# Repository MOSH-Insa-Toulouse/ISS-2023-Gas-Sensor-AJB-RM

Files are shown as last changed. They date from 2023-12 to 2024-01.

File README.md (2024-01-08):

# ISS 2023: Gas sensor 

### Authors
Romain Moulin & Aude Jean-Baptiste, 5ISS 2023-2024

# Introduction
The objective of this project is to integrate a gas sensor that we made ourselves during a training period at AIME (Atelier Interuniversitaire de Micro Electronique) and send its data over a Lora network to a dashboard to see and analyse the values.

# Initiation to Electronics and Arduino programming
As we both come from a computer science background (4IR-SC), we used the first labs as an introduction to Arduino and Kicad. We tested some small projects from simply making a LED from an Arduino blink to collecting data sent by a Nunchunck (A nintendo WII controller). We also designed an android application able to communicate and interact with an arduino.

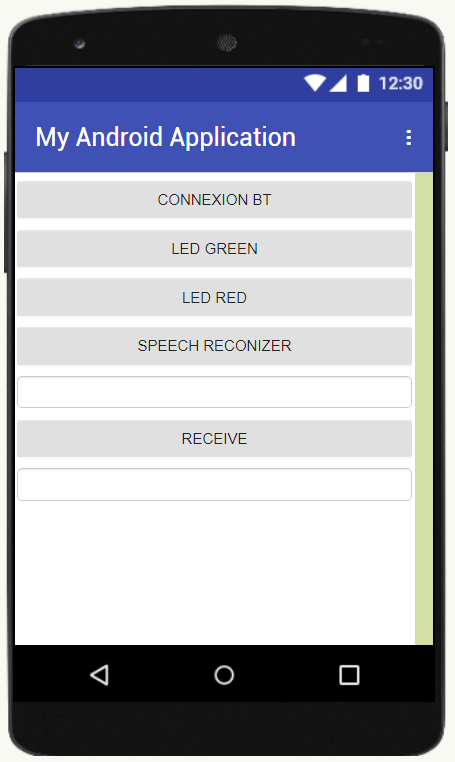
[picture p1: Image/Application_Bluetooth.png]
Screenshot of our Android application
 *Screenshot of our Android application*

These first sessions were really usefull to understand the basics of Arduino programming and electronics. These small projects were a good introduction to the real project of this course.

# Lora network integration

To begin our project, we first tried to connect an arduino to the Lora network. To do so, we used a RN2483 chip made by Microship which is a module that is able to communicate on a Lora network. As this chip only has tiny connectors, we needed to weld the component to a board that would have bigger connectors for the communication with the arduino. The following image features the board with an antenna for the 868MHz frequency band. 

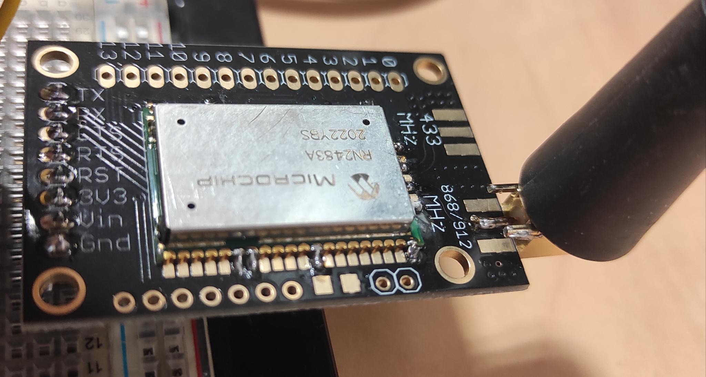
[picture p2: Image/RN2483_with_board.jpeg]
RN2483 Module weld on the board
 *RN2483 Module weld on the board*

After this step, we were able to connect our arduino to the INSA's Lora network. For this, we used *The Things Network* library for arduino, the code is available [here](./Arduino-Code/lora_connection/lora_connetion.ino).
For this, we had used the otaa authentication method. We got the device ID using the library and the application ID and key on the [chirpstack's INSA website](https://srv-chirpstack.insa-toulouse.fr/#/login) (please note that this server is only available if you are directly connected to INSA's network, or using a VPN). 

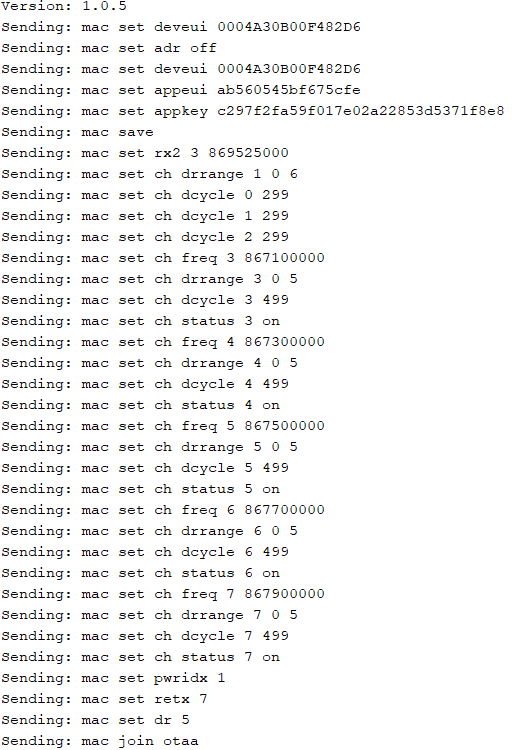
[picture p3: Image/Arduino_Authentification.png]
Authentication of the arduino to the Lora network
 *Authentication of the arduino to the Lora network*

# Integration of the MQ-3B gas sensor

With the established connection, we had to send data to the gateway in order to retrive it and display it on a dashboard. As a first implementation of this application we connected an alreay made gas sensor which is the MQ-3B gas sensor to our arduino. The final montage of our circuit is the following:

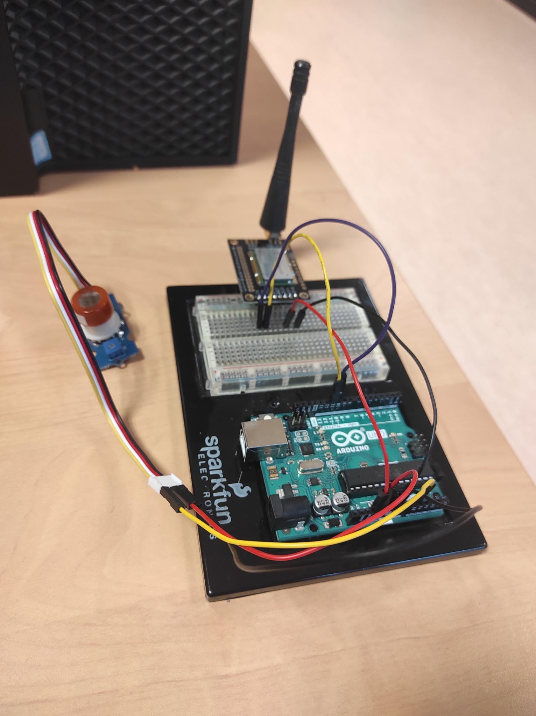
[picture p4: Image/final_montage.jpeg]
Montage of the circuit with the MQ-3B gas sensor
 *Montage of the circuit with the MQ-3B gas sensor*

After that we changed our arduino code to read the value from the gas sensor and send it to our LoRa network. As the max value we can get from the sensor is 1024, we encoded the information on 2 bytes before sending it.

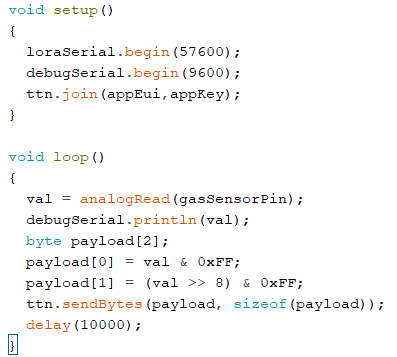
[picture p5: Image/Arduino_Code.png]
*Our arduino setup and loop functions
 *Our arduino setup and loop functions*

# Design of a node-red application

As the data is received by the LoRa network, we could visualize it on the chirpstack web page. However, it is not fitted for a real usage of our gas sensor. A user of gas sensor would like to see the state of the sensor in real time in a dashboard. To do so, we decided to use node-red and MQTT.

MQTT is a communication protocol particulary used for IoT devices. With this protocol there are two kind of nodes, the publisher and the subscribers. Publishers publish data in a topic and subscriber get all the data published on a specific topic. This protocol is supported by chirpstack which automatically upload the data it receives in a MQTT topic. 

Node-red is a web-browser flow editor that helps to easily connect flows. It provides visual coding with blocks for the ease of conception. It also implements dashboard library to display the data is user friendly dahsboards. We used a MQTT subscribe block to get the data from chirpstack that we pipe into a javascript function that decodes the data (it is encoded in base64 by chirpstack). Finaly we send the decoded data to a dashboard block to visualize the data.

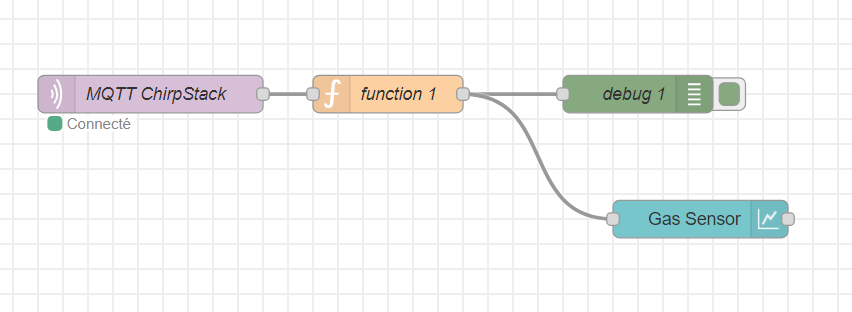
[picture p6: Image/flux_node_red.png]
The node-red flow
 *The node-red flow*

# Test of the MQ-3B solution

To test our sensor, we putted hydroalcoholic gel near it to see if we could see it on our dashboard. This experience was a succes and we were able to see on the dashboard the increase of the gas rate near the sensor.

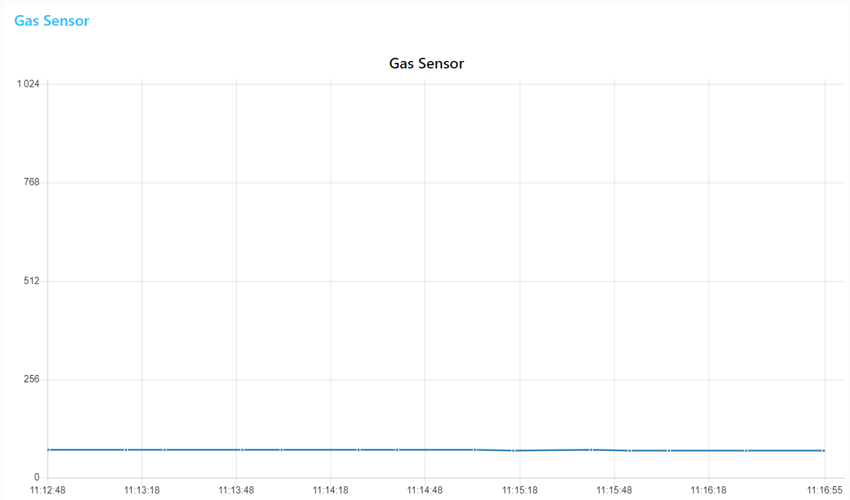
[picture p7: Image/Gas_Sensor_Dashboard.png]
Dashboard for the witness experience in ambient air
 *Dashboard for the witness experience in ambient air*

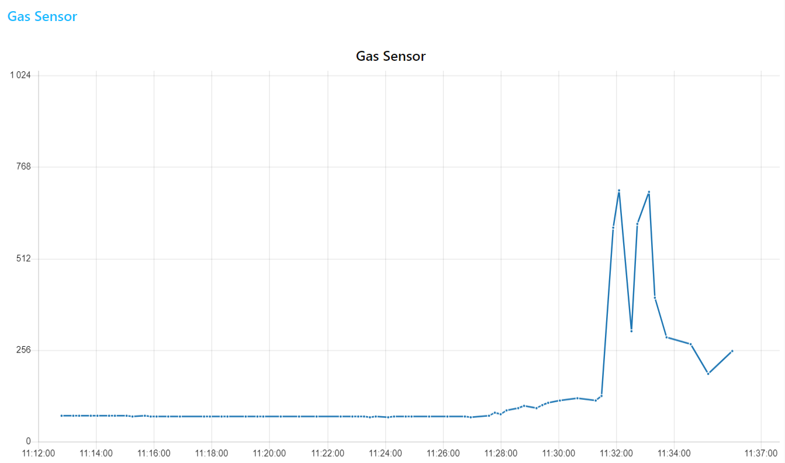
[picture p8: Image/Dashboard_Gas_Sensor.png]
Dashboard for the experience with alcoholic gel
 *Dashboard for the experience with alcoholic gel*

# Integration of our gas sensor from AIME 

The specifications of our gas sensor are detailed in the datasheet (see below). In order to replace the commercial sensor (MQ-3B) by our gas sensor in our previously detailed monitoring solution with Lora and node-red, we need to follow various steps. 

Indeed, our sensor per se is passive; changes in its resistance allow us to monitor gas presence. We will power and control the sensor through an arduino uno and get its data with the ADC (analog digital converter),  like we did with the MQ-3B. 

The screenshots on the following part have been extracted from our Kicad project, that you can find [here](./MOSH). 

## Transimpedance amplifier

The first stage to treat sensor data is a transimpedance amplifier that will allow us to shape the signal for it to be detected by the arduino's ADC. This stage contains 3 low-pass filters with the following cut-off frequencies and roles: 
- filter 1: 16Hz - this filter is here to eliminate as much noise from the sensor as possible
- filter 2: 1.6Hz - this filter should get rid off the 50Hz noise
- filter 3: 1.6kHz - this filter should adapt the signal to the arduino's ADC 

This circuit was simulated on LTSpice to test the properties of the different filters and of the transimpedance amplifier per se. You can find all the related work in [this directory](./ltspice-stuff)

The transimpedance amplifier is featured in the following image. 

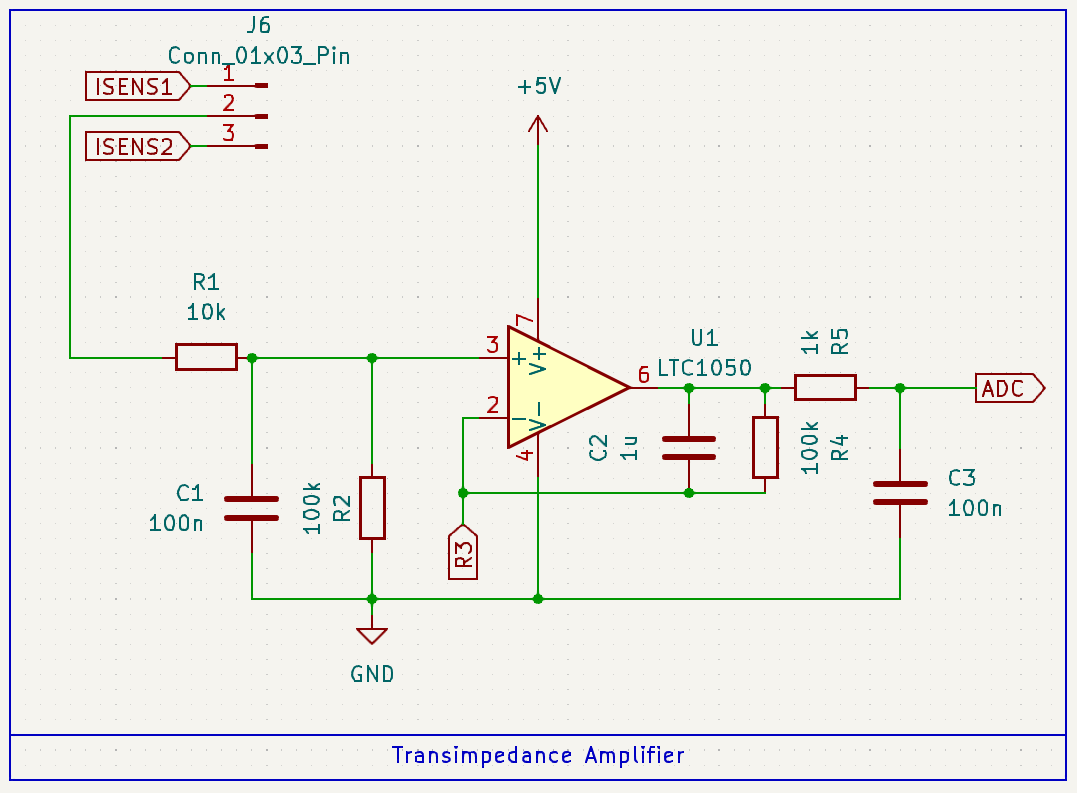
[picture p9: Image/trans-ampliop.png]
Transimpedance amplifier schematic
 *Our transimpedance amplifier stage*

You might notice that what we called R3 on this schematic is not a resistor. Indeed, we need to apply a variable resistance to the reverser entry of the operationnal amplifier. This variable resistor is detailed in the next subsection. 

## Digital potentiometer

We use a digital potentiometer as a variable resistor. We choose a MCP41100. This component is powered on 5V and controlled by the arduino via SPI (3 pins: Clock, MOSI and CS). 

The following image features the schematic for this component. 

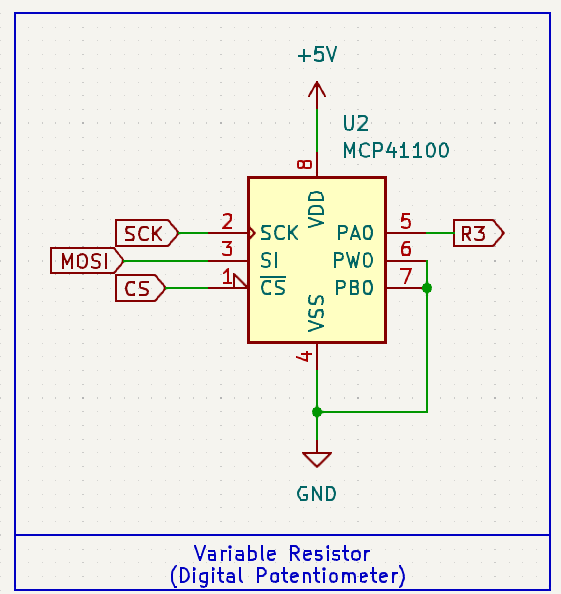
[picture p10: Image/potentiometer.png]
Digital Potentiometer schematic
 *Montage for the digital potentiometer*

## Heating resistor controlled via PWM 

Our sensor is a "smart sensor". It contains a heating resistor (a polysilicon resistor) as well as a temperature sensor (an aluminium resistor). The heating resistor needs to be controlled by the arduino via PWM, which is possible thanks to the following montage with a IRF540N transistor. 

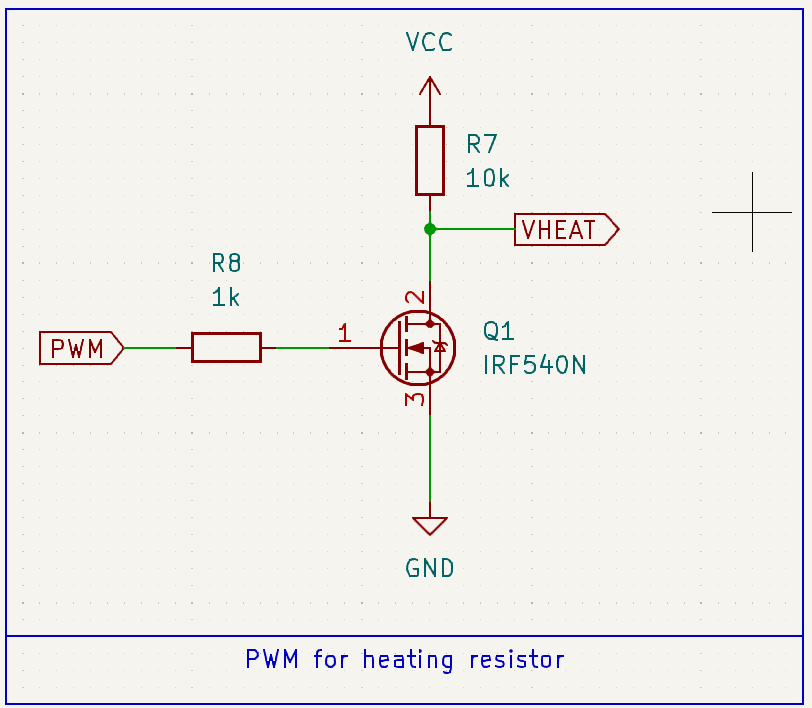
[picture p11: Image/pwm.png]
PWM montage
 *PWM montage with transistor*

## Sensor connections 

We designed a symbol in Kicad for our sensor. You can find the library [here](./Library_AJB_RM_0). The symbol is associated with the Package_TO_SOT_THT:TO-5-10 footprint, on which our sensor has been mounted. 

The schematic of the sensor connections is featured below. 

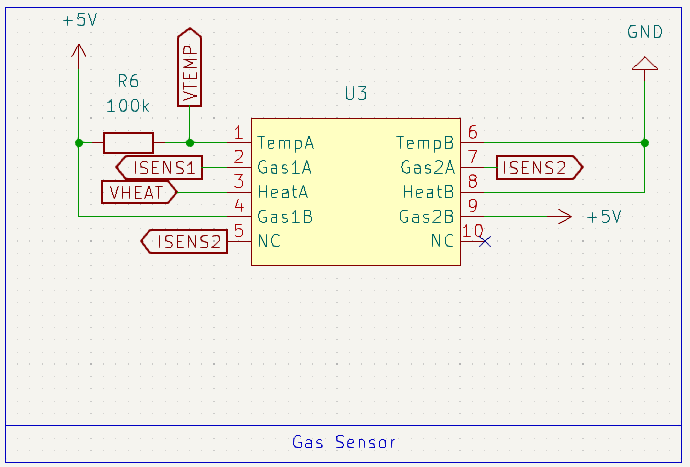
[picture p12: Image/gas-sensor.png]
Gas sensor connections
 *Our gas sensor connections on the schematic*

## PCB design 

We designed a PCB to integrate our sensor with all the previously described stages. 

This PCB is featured in the following figure. 

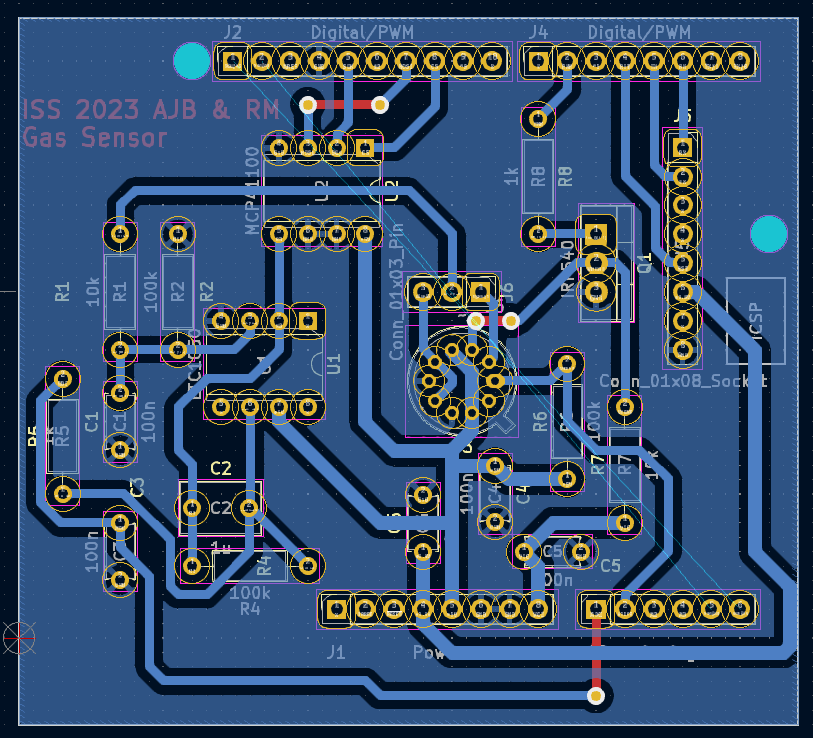
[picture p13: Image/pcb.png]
PCB view
 *Our PCB for sensor integration*

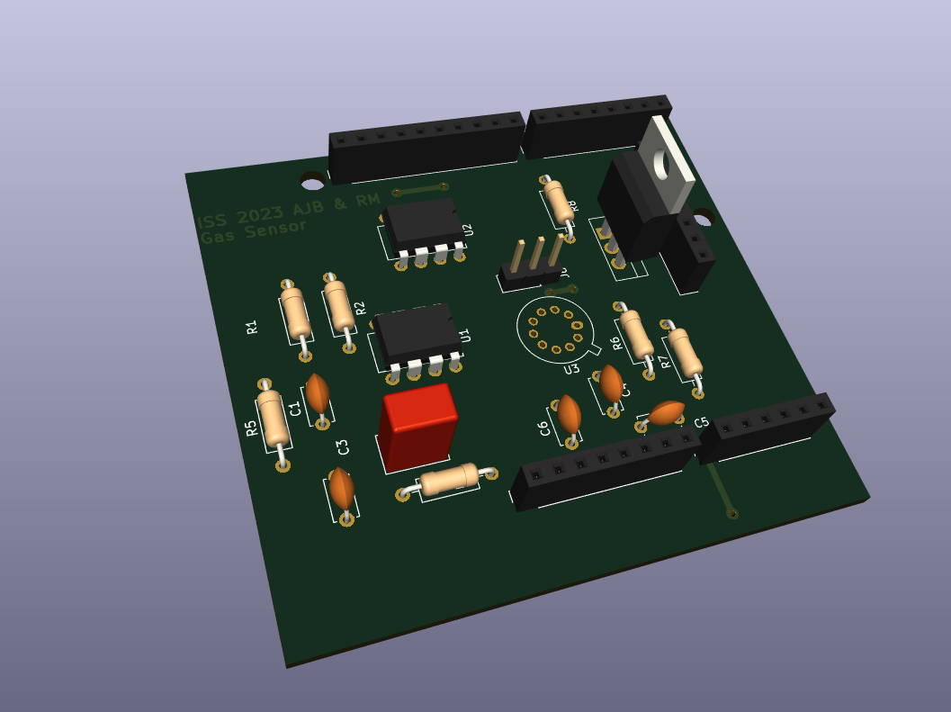
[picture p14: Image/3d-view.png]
3D view
 *A nice 3D view of our PCB*

We followed these clearance and track size rules: 

Name|Clearance|Track Width|Via size|Via Hole
---|---|---|---|---
Default	| 0.2 mm	| 0.25 mm	| 0.6 mm	| 0.4 mm	
power	| 0.2 mm	| 1.2 mm	| 0.6 mm	| 0.4 mm	

**Minimum clearance: 0.8mm**

**Minimum track width: 0.8mm**

**Minimum via diameter: 1.5mm**

This PCB is far from perfect as we are two computer science students. We did not had the time to print it and integrate it with a real sensor. 

We can cite some ways to improve it if we were to continue the project:
- the vias could be bigger and better placed, especially the one for the ADC track.
- there is some clearance violations on the gas sensor, because we had to adopt less stricts rules to be able to route the sensor's tracks.
- there are quite a lot of right angles on the 5V track that we were not able to eliminate but that could be problematic.
- some angles on the PCB are acute, even if we tried to avoid them.
- you can notice that we connected one of the non connected pins of the sensor to ISENS2 to facilitate routing.

# Datasheet of our gas sensor from AIME 

We realized a datasheet for our gas sensor that you can find [here](./Datasheet.pdf). 

You might realize that it does not include the graphs that show the evolution of sensor's resistance with gas presence, because we were not given this year's data from AIME training period (and our nano particles synthesis did not worked as expected anyway). Furthermore, the previous years' data were uncomplete as they were not labeled with the gas' names.  

# To go further

As we did not had time to print the PCB, some obvious steps to bring our work further would be: 
- print the PCB
- weld all the components
- test the electrical circuits
- write code to control the heating resistor and the potentiometer
- create a retrocontrolled loop to manage sensor's temperature
- test the sensor reactivity to NH<sub>3</sub> and C<sub>2</sub>H<sub>6</sub>O 
- test the whole system with Lora transmission of the data and display in the node-red application
- enjoy a fully smart sensor ;-) 

# Conclusion

This project was a great start to finish introduction to the world of sensors, from fabrication to integration of the data on user-friendly dashboards. We were able to develop or reinforce skills in various fields like Lora communication, node-red applications, or PCB design.

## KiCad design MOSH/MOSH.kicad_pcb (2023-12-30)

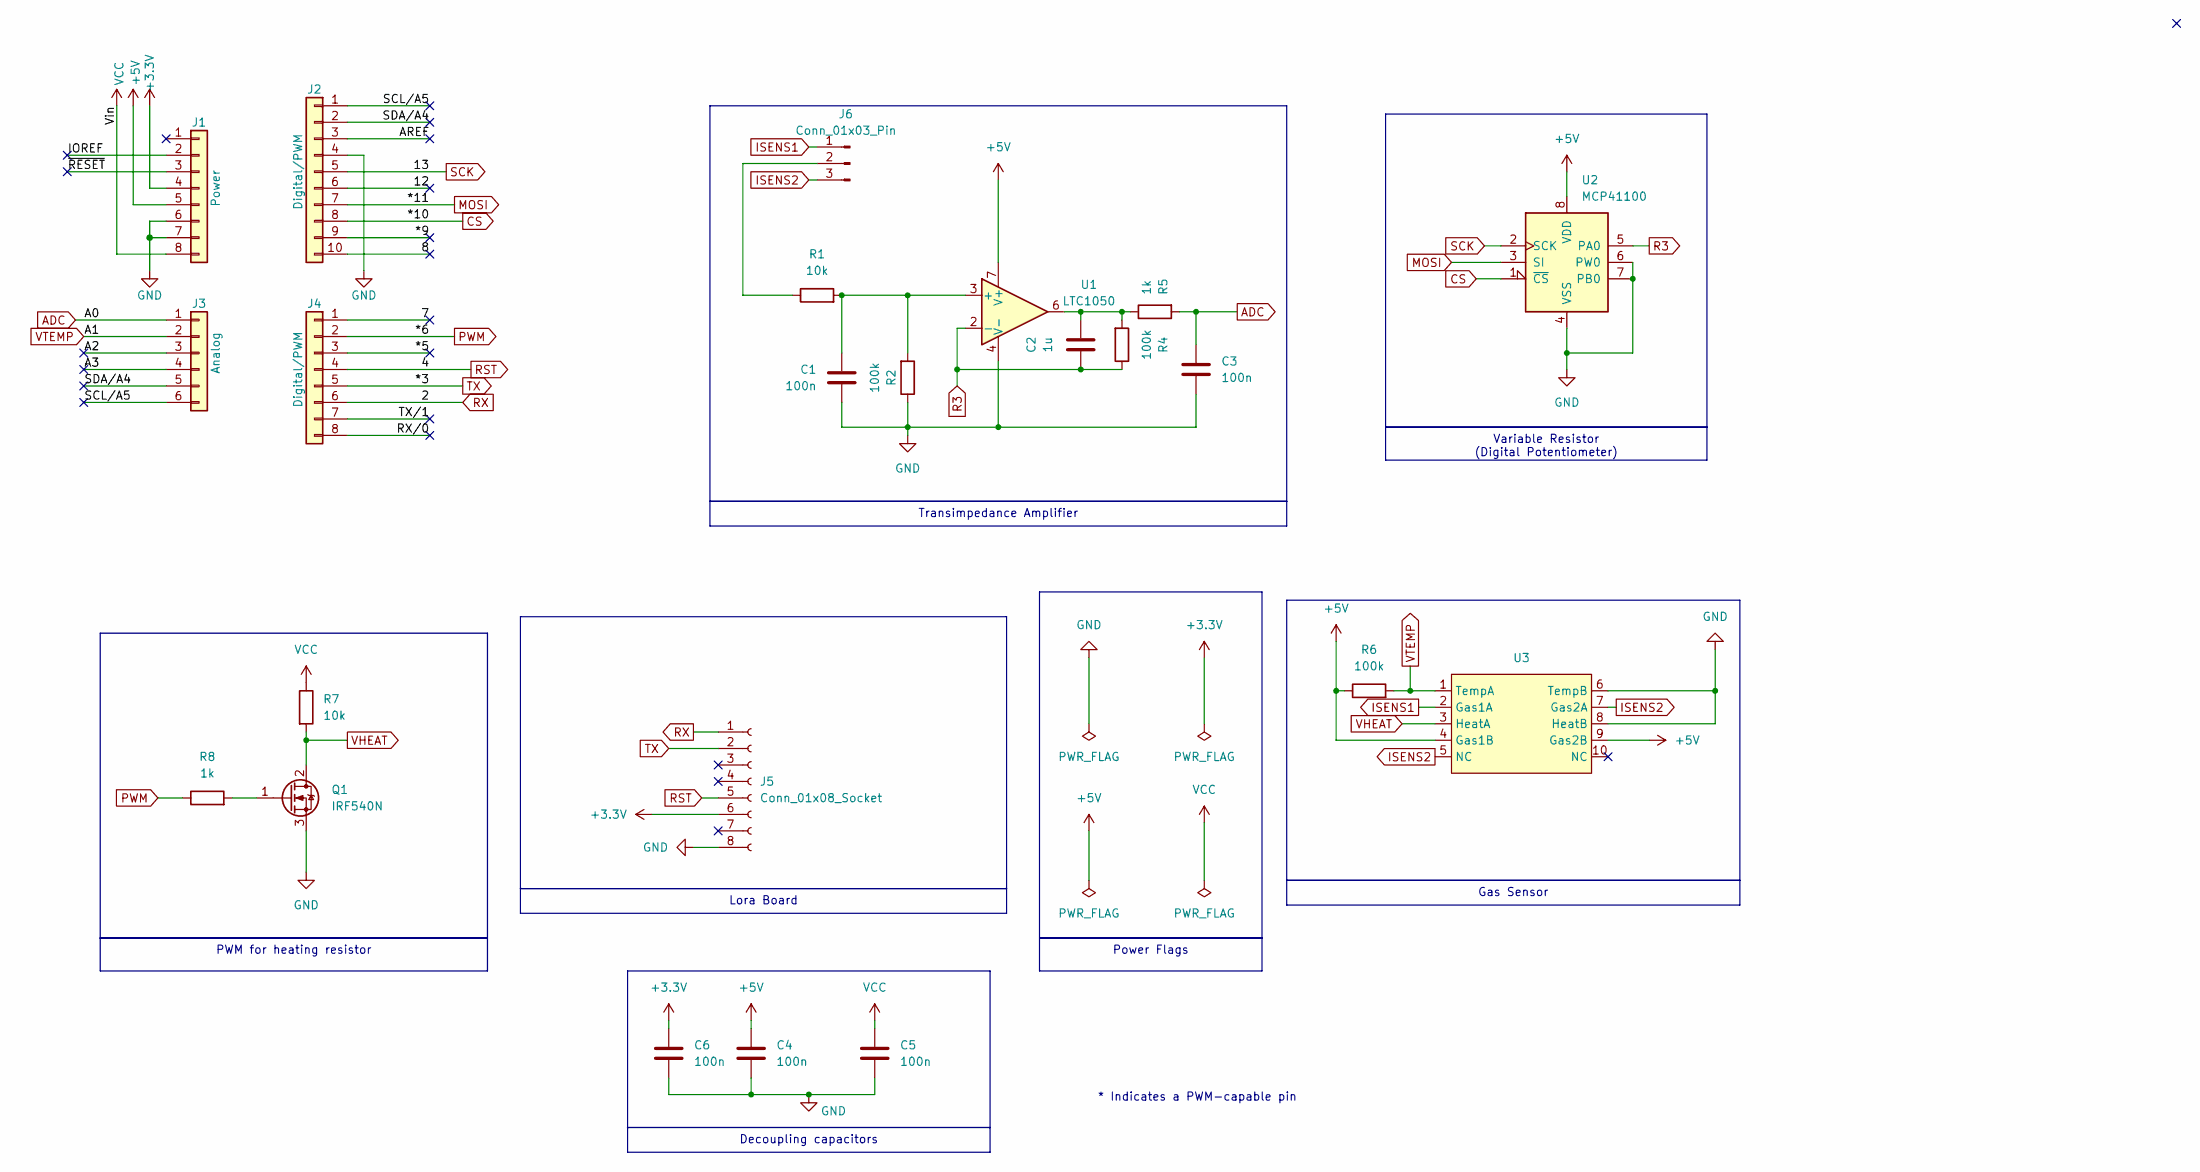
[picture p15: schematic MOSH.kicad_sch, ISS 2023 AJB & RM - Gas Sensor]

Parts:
C1, C3, C4, C5, C6: 100n; C_Disc_D4.7mm_W2.5mm_P5.00mm
C2: 1u; C_Rect_L7.0mm_W4.5mm_P5.00mm
J1: Power; PinSocket_1x08_P2.54mm_Vertical
J2: Digital/PWM; PinSocket_1x10_P2.54mm_Vertical
J3: Analog; PinSocket_1x06_P2.54mm_Vertical
J4: Digital/PWM; PinSocket_1x08_P2.54mm_Vertical
J5: Conn_01x08_Socket; PinSocket_1x08_P2.54mm_Vertical
J6: Conn_01x03_Pin; PinHeader_1x03_P2.54mm_Vertical
Q1: IRF540N; TO-220-3_Vertical
R1, R7: 10k; R_Axial_DIN0207_L6.3mm_D2.5mm_P10.16mm_Horizontal
R2, R4, R6: 100k; R_Axial_DIN0207_L6.3mm_D2.5mm_P10.16mm_Horizontal
R5, R8: 1k; R_Axial_DIN0207_L6.3mm_D2.5mm_P10.16mm_Horizontal
U1: LTC1050; DIP-8_W7.62mm
U2: MCP41100; DIP-8_W7.62mm
U3: TO-5-10

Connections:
+3.3V: C6.1, J1.4, J5.6
+5V: C4.1, J1.5, R6.1, U1.7 (V+), U2.8 (VDD), U3.4 (Gas1B), U3.9 (Gas2B)
/7: J4.1
/8: J2.10
/12: J2.6
/*5: J4.3
/*9: J2.9
/A2: J3.3
/A3: J3.4
/AREF: J2.3
/IOREF: J1.2
/RX/0: J4.8
/SCL/A5: J2.1, J3.6
/SDA/A4: J2.2, J3.5
/TX/1: J4.7
/~RESET: J1.3
ADC: C3.1, J3.1, R5.2
CS: J2.8, U2.1 (~CS)
GND: C1.1, C3.2, C4.2, C5.2, C6.2, J1.6, J1.7, J2.4, J5.8, Q1.3 (S), R2.1, U1.4 (V-), U2.4 (VSS), U2.6 (PW0), U2.7 (PB0), U3.6 (TempB), U3.8 (HeatB)
ISENS1: J6.1, U3.2 (Gas1A)
ISENS2: J6.3, U3.5 (NC), U3.7 (Gas2A)
MOSI: J2.7, U2.3 (SI)
unnamed: C2.2, R4.2, R5.1, U1.6
unnamed: J6.2, R1.1
unnamed: Q1.1 (G), R8.2
unnamed: C1.2, R1.2, R2.2, U1.3 (+)
PWM: J4.2, R8.1
R3: C2.1, R4.1, U1.2 (-), U2.5 (PA0)
RST: J4.4, J5.5
RX: J4.6, J5.1
SCK: J2.5, U2.2 (SCK)
TX: J4.5, J5.2
VCC: C5.1, J1.8, R7.1
VHEAT: Q1.2 (D), R7.2, U3.3 (HeatA)
VTEMP: J3.2, R6.2, U3.1 (TempA)

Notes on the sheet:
Decoupling capacitors
Variable Resistor (Digital Potentiometer)
PWM for heating resistor
Transimpedance Amplifier
Lora Board
Gas Sensor
Power Flags
* Indicates a PWM-capable pin

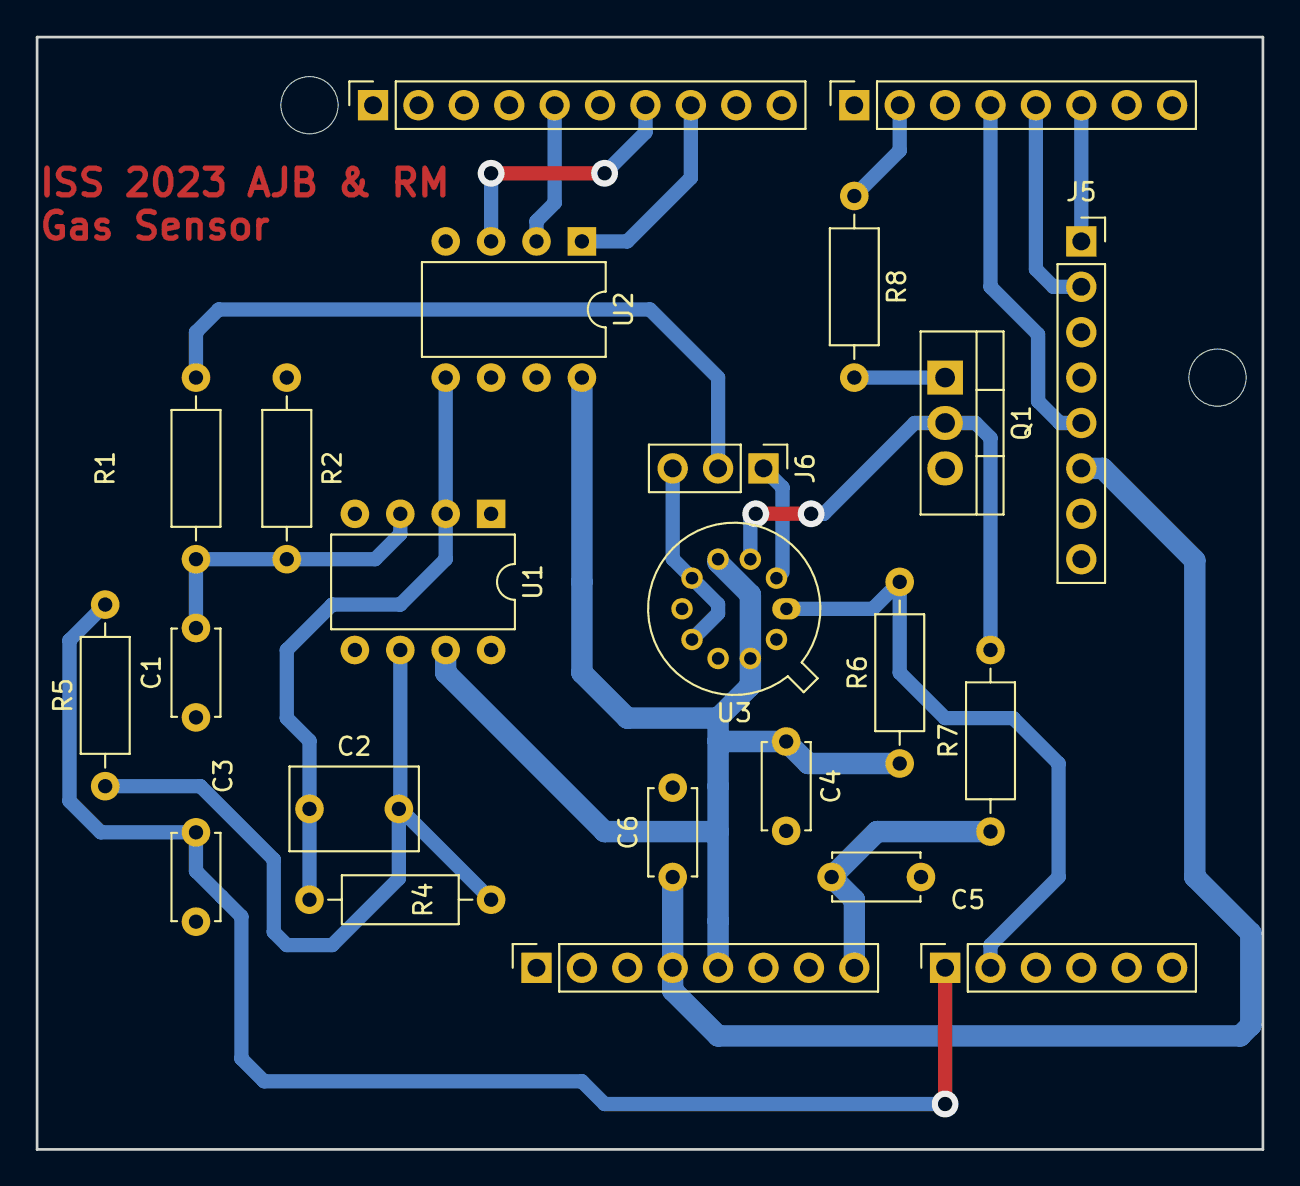
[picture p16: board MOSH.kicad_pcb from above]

Board: 2 copper layers, 68.6 x 62.2 mm, 25 parts (0 on the bottom side), 23 nets.

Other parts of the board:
MH1, MH3: MountingHole_3.2mm

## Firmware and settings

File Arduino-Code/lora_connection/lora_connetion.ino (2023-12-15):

#include <TheThingsNetwork.h>
#include <SoftwareSerial.h>

#define loraSerial mySerial
#define debugSerial Serial

// Replace REPLACE_ME with TTN_FP_EU868 or TTN_FP_US915
#define freqPlan TTN_FP_EU868


const byte txPin = 11;
const byte rxPin = 10;
const int gasSensorPin = 0;

SoftwareSerial mySerial (rxPin,txPin);
TheThingsNetwork ttn(loraSerial, debugSerial, freqPlan);


const char *appEui = "ab560545bf675cfe";
const char *appKey = "c297f2fa59f017e02a22853d5371f8e8";
int val = 0;

void setup()
{
  loraSerial.begin(57600);
  debugSerial.begin(9600);
  ttn.join(appEui,appKey);
}

void loop()
{
//  debugSerial.println("Device Information");
//  debugSerial.println();
//  ttn.showStatus();
//  debugSerial.println();
//  debugSerial.println("Use the EUI to register the device for OTAA");
//  debugSerial.println("-------------------------------------------");
//  debugSerial.println();
//  byte data[2];
//  data[0] = 0x11;
//  data[1] = 0x10;
//  ttn.sendBytes(data,sizeof(data));
//  debugSerial.println("Byte envoyé");
  val = analogRead(gasSensorPin);
  debugSerial.println(val);
  byte payload[2];
  payload[0] = val & 0xFF;
  payload[1] = (val >> 8) & 0xFF;
  ttn.sendBytes(payload, sizeof(payload));
  delay(10000);
}

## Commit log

2023-12-13 Kicad project
    [MOSH.kicad_pcb, MOSH.kicad_sch]
2023-12-13 pcb schematic transimpedance amplifier, variable resistance, lora board and gas sensor
    [MOSH.kicad_sch]
2023-12-13 pcb schematic fini
    [MOSH.kicad_sch]
2023-12-13 j'essaie de mettre la librairie sur git aussi
2023-12-15 add all footprints and start rooting
    [MOSH.kicad_pcb, MOSH.kicad_sch]
2023-12-15 router avec Allan!
    [MOSH.kicad_pcb]
2023-12-15 ajouter des règles de routage pour mettre dans readme /rapport
2023-12-19 je pensais avoir commit la dernière fois
    [MOSH.kicad_pcb]
2023-12-19 je route
    [MOSH.kicad_pcb, MOSH.kicad_sch]
2023-12-20 routage fini oui j'ai fait des vias, du coup il manque plus que le plan de masse
    [MOSH.kicad_pcb]
2023-12-20 commencer le plan de masse, mon routage il est tout cassé du coup
    [MOSH.kicad_pcb]
2023-12-21 presque fini routage il manque plus que quelques détails ; penser à checker les règles electrique
    [MOSH.kicad_pcb, MOSH.kicad_sch]
2023-12-22 j'ai fini de router, c'est pas opti mais ça existe
    [MOSH.kicad_pcb]
2023-12-30 run design rules check and correct some things
    [MOSH.kicad_pcb]
2023-12-30 décaler les titres
2023-12-30 add schematic screenshots
    [MOSH.kicad_sch]
2023-12-30 add title
    [MOSH.kicad_pcb]
2023-12-30 Il est raisonnable de commit
2023-12-30 images for readme
    [MOSH.kicad_sch]
2023-12-30 finir partie sur pcb
2023-12-30 Ajout de la datasheet
